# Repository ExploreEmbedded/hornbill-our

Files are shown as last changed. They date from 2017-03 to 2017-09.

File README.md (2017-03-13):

# hornbill-our
Open Univeral Remote with Hornbill ESP32 dev tools. BLE IR Bridge for device control. This is demonstration of what is possible with Hornbill ESP32 platform. To know more and support our work visit:
https://www.crowdsupply.com/explore-embedded/hornbill
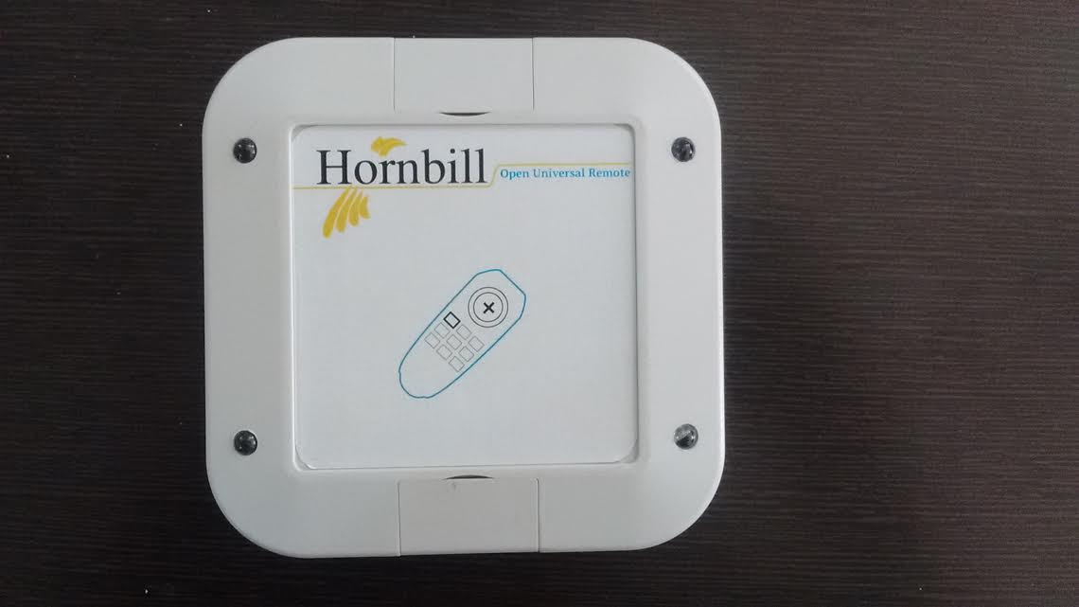
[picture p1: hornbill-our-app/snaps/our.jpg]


#ToDo
If there is enough interest in the project, we would like to add the following features:
<ul>
<li>
 Add other major IR protocols. At least the once supported by IRRemote Arduino Library 
</li>
<li>
Integrate Irdb.tk api so that remotes can be add to the app during the setup. This would require internet connection only during setup. 
</li>

<li>
RemoteMaker: Add app/firmware feature to create remotes that are not available in the database.
</li>

</ul>

If you've anyother suggestions that could be helpful, please raise on issue here on the repo. 
 
# App Screens
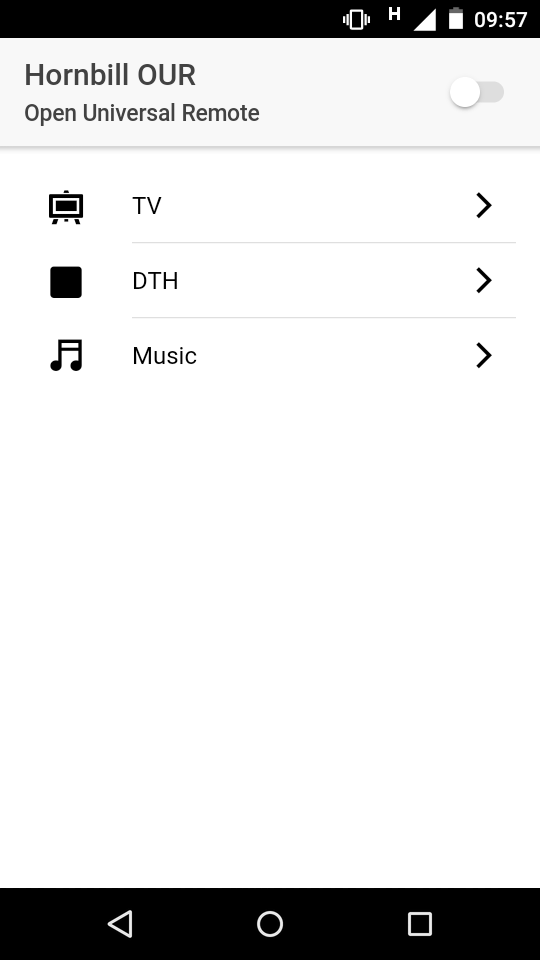
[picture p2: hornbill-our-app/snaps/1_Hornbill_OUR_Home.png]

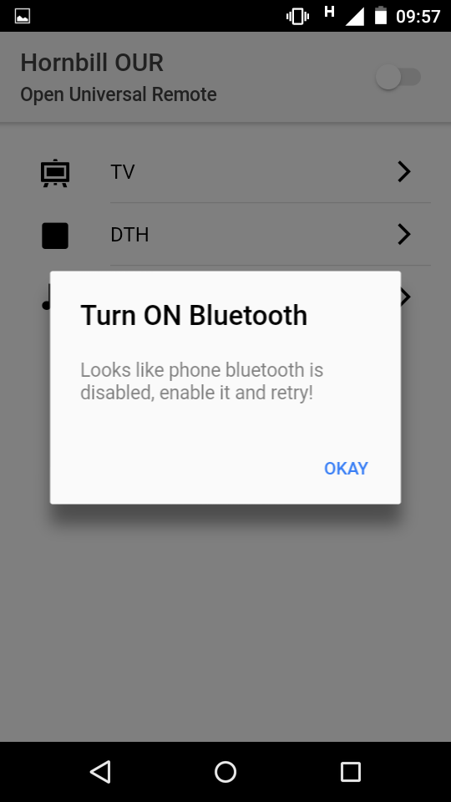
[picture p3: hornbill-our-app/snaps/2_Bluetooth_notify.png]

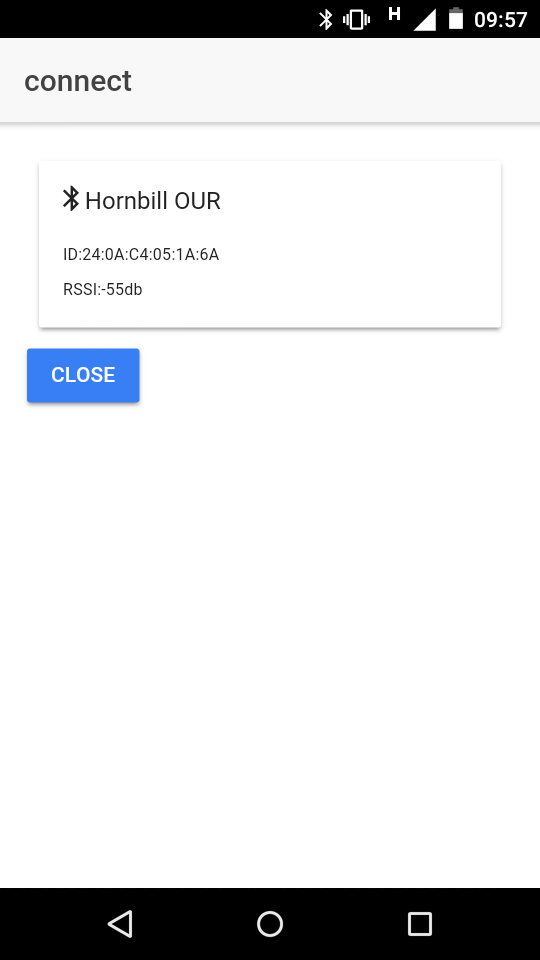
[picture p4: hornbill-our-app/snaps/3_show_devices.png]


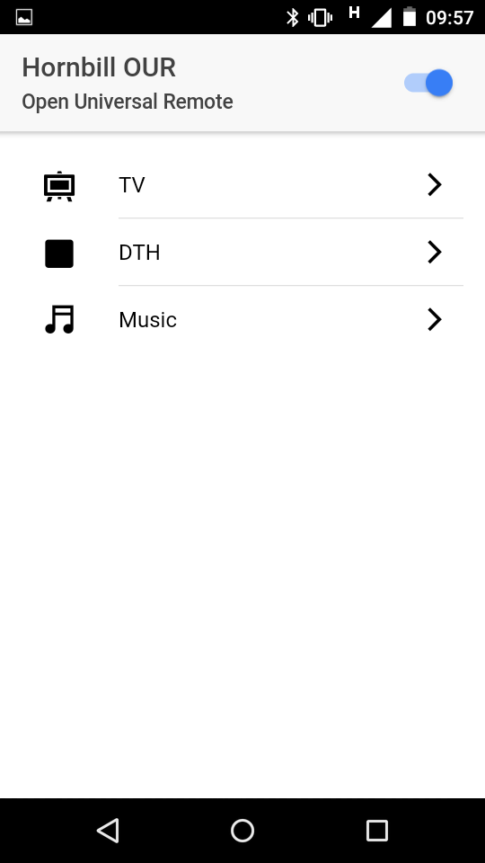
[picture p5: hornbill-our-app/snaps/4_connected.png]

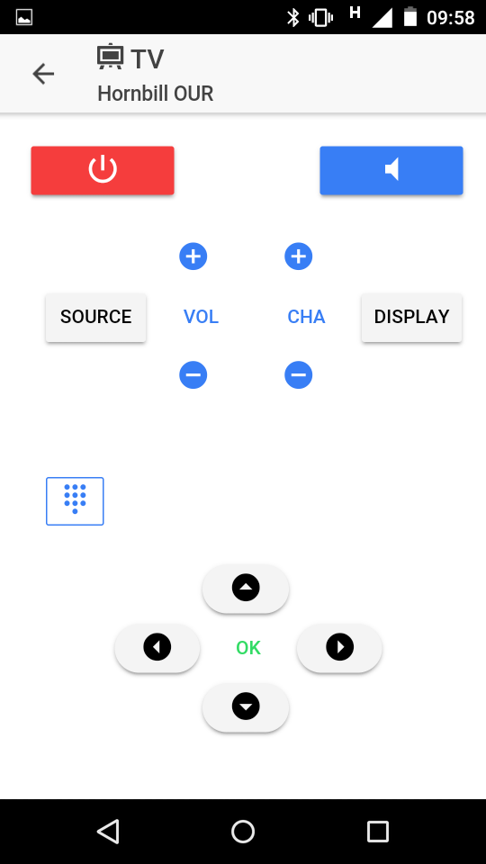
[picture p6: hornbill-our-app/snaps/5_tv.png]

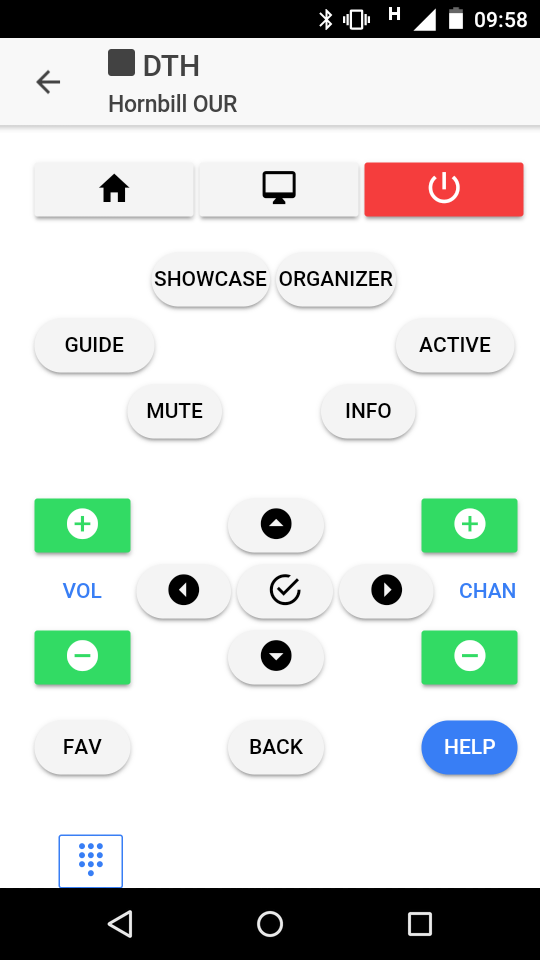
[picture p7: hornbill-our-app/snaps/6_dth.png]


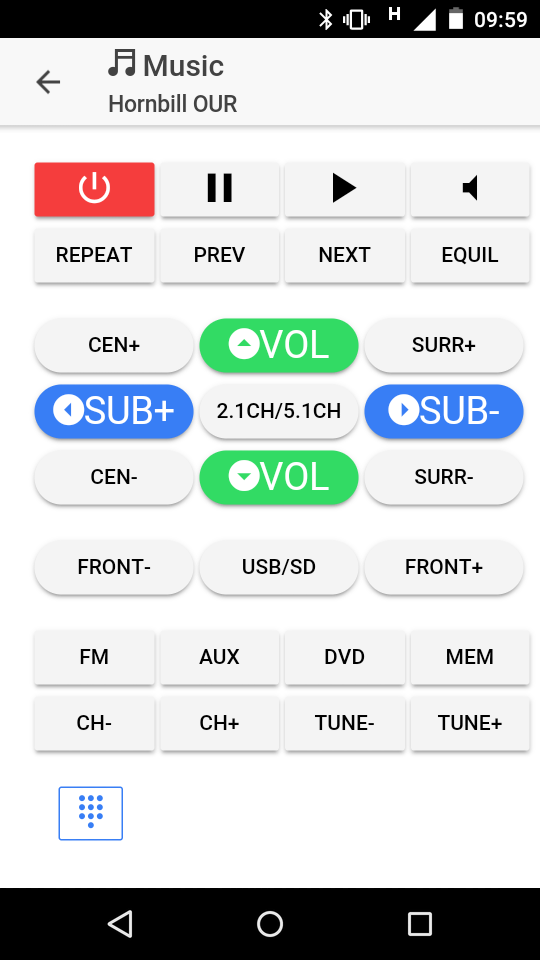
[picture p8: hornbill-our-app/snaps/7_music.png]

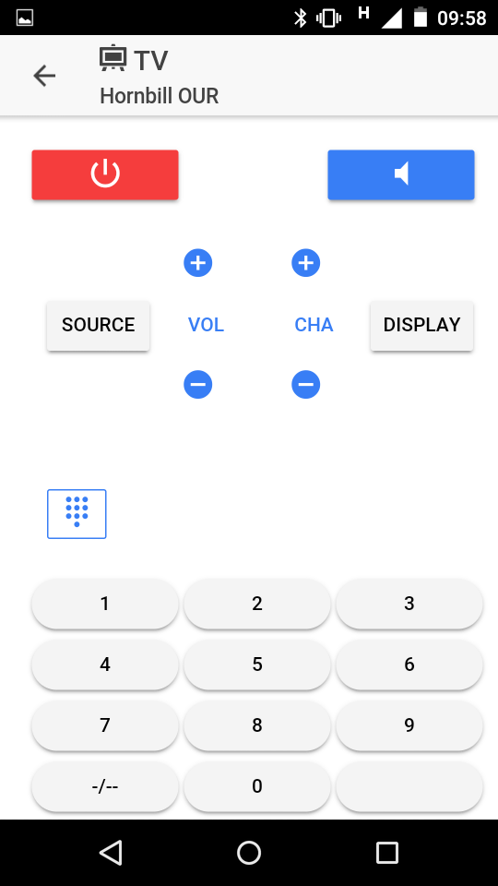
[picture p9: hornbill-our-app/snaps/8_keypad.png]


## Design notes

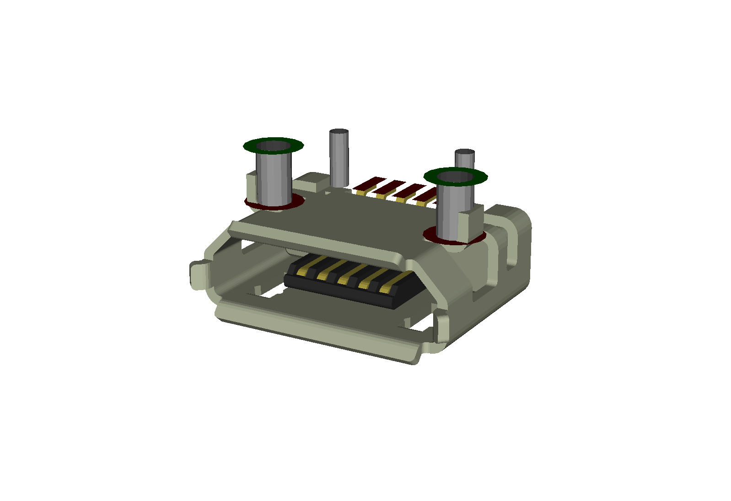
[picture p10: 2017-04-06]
Hardware/PCB/3d/micro-usb-female-type-b-connector-smd-1.snapshot.3/Renderings/AB2_USB_MICRO_SMD_2.png

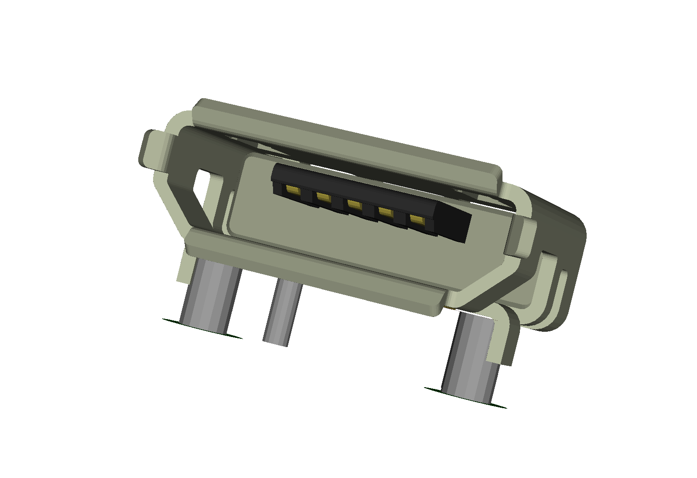
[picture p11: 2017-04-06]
Hardware/PCB/3d/micro-usb-female-type-b-connector-smd-1.snapshot.3/Renderings/AB2_USB_MICRO_SMD.png

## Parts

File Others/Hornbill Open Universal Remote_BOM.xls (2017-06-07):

Id | Designator | Package | Qty | Designation
1 | D2 | LED-0603_NEW | 1 | Blue
2 | D3 | LED-0603_NEW | 1 | LED
3 | C1 | C_1206 | 1 | 100uF
4 | C2 | C_0603 | 1 | 100nF
5 | C3 | C_0603 | 1 | 1uF
6 | C4,C5 | C_0603 | 2 | 15pF
7 | C6 | C_0603 | 1 | 2.2uF
8 | C8,C7 | C_0603 | 2 | 0.1uF
9 | CON1 | USB_Micro-B_SMD_NEW_1 | 1 | USB-MINI-B
10 | D5,D6,D9,D10 | LED-5MM | 4 | LED
11 | M1 | ESP-32S | 1 | ESP-WROOM-32
12 | P2 | Pin_Header_Straight_1x03_Pitch2.54mm | 1 | CONN_01X03
13 | R2,R10 | R_0603 | 2 | 10K
14 | R6,R9 | R_0603 | 2 | 1K
15 | R7,R8,R3,R4,R5,R11 | R_0603 | 6 | 0E
16 | R13,R23 | R_0603 | 2 | 0R
17 | R18 | R_0603 | 1 | 680R
18 | R19,R20 | R_0603 | 2 | 12K
19 | R21,R22 | R_0603 | 2 | 47R
20 | SW1,SW2 | smd_push2_New | 2 | SW_PUSH
21 | U1 | SOT-23-5 | 1 | AP2112K
25 | Y1 | SMD_RTC_Crstl | 1 | 32.768KHz RTC Crystal
26 | Q2 | SOT-23 | 1 | Q_NPN_BEC
27 | Q3,Q4 | SOT-23 | 2 | S8050
28 | P1,P3,P4,P5,P6,P7,P8,P9,P10,P11,P12,P13,P14,P15 | EE_Pin_Header_Straight_1x14_Pitch2.54mm | 14 | CONN_01X14
29 | F1 | Fuse_500mA | 1 | 500mA
30 | U9 | cp2102_xl2 | 1 | CP2102

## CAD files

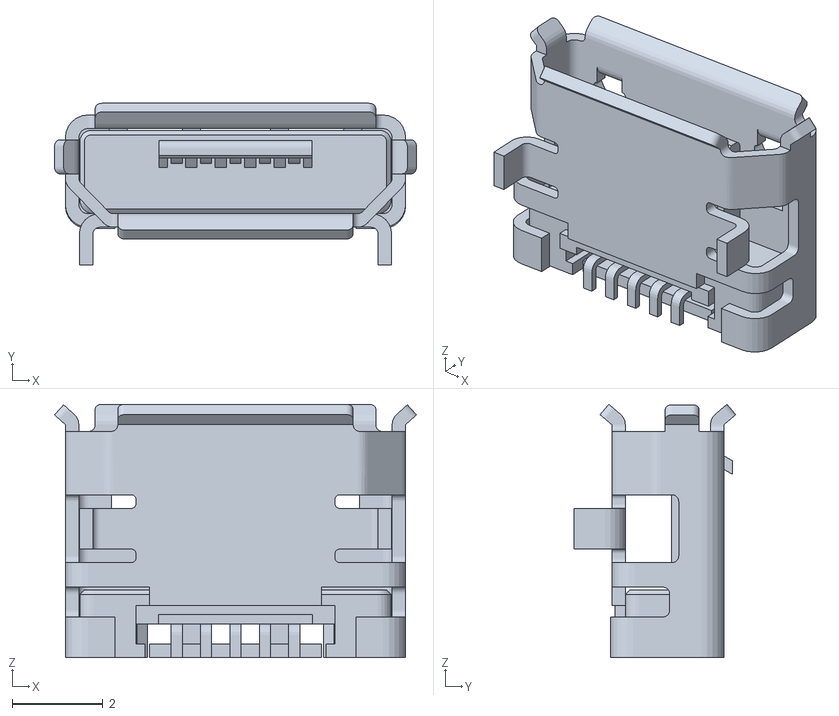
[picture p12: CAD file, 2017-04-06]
Hardware/PCB/3d/micro-usb-female-type-b-connector-smd-1.snapshot.3/AB2_USB_MICRO_SMD.stl
8.00 x 3.57 x 5.60

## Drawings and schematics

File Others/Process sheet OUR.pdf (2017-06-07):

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

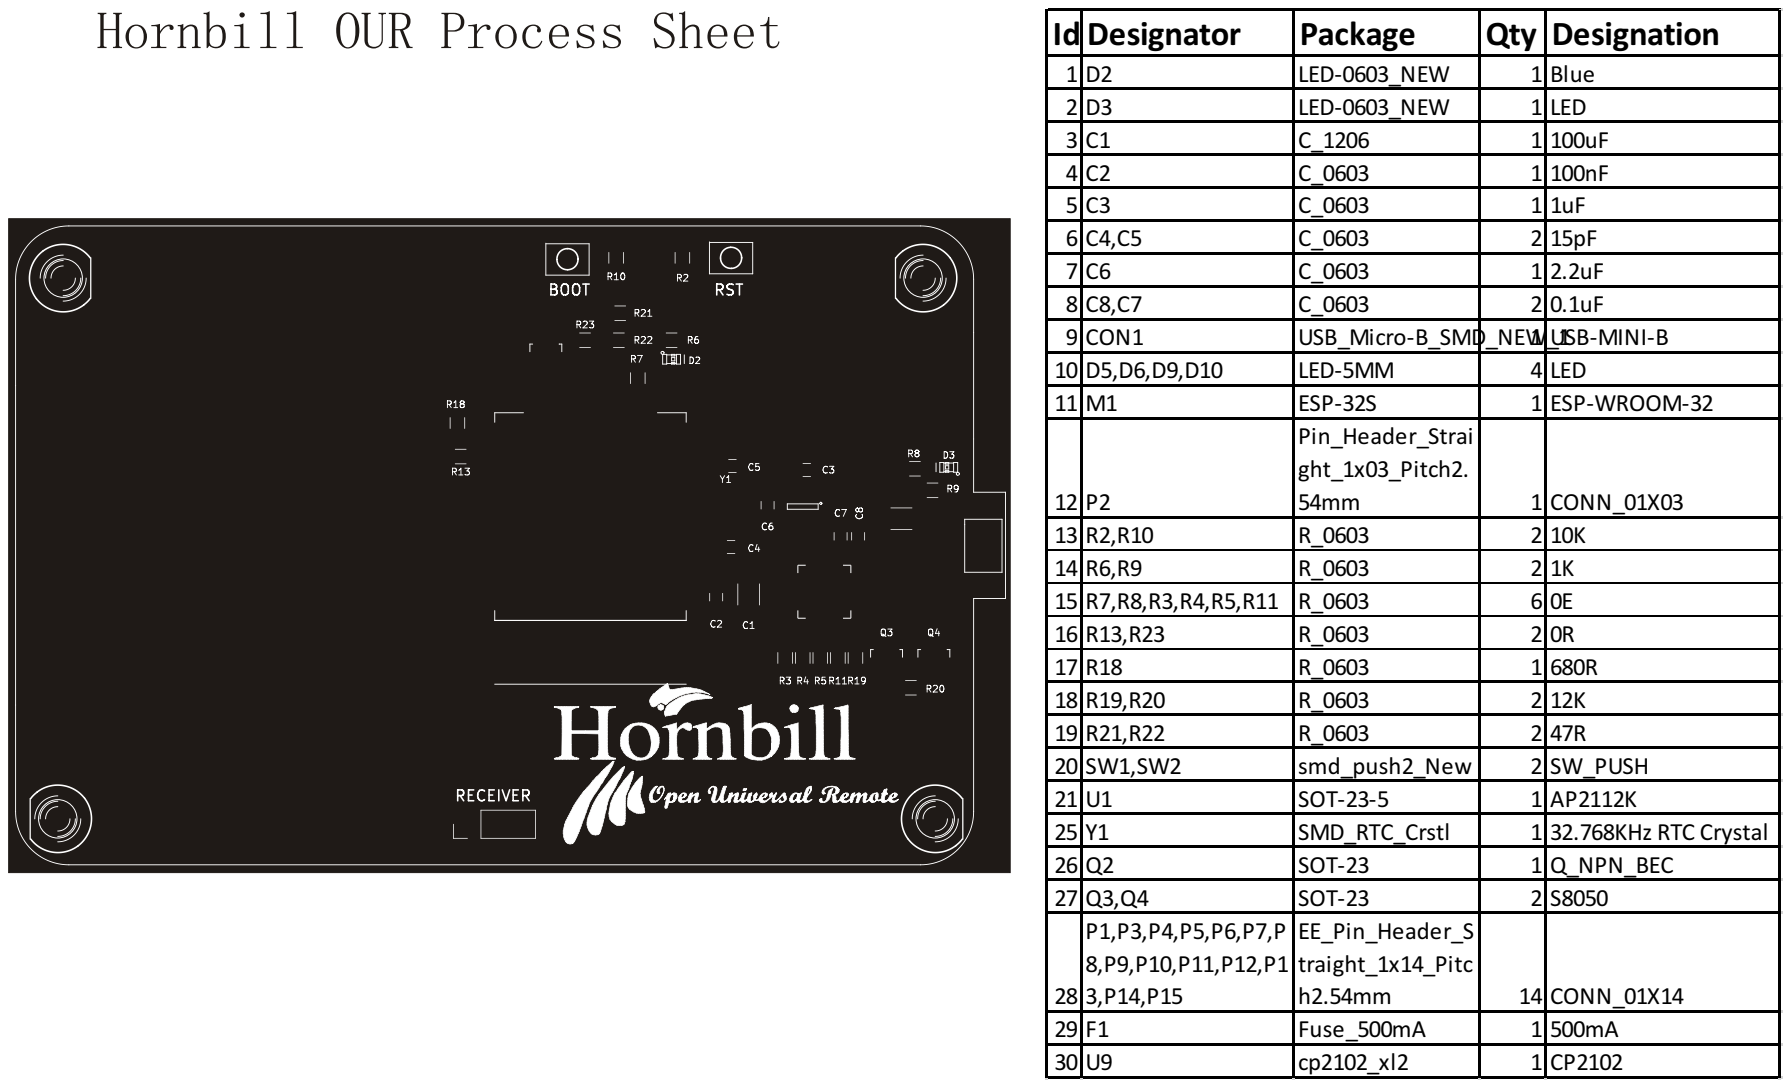
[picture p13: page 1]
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

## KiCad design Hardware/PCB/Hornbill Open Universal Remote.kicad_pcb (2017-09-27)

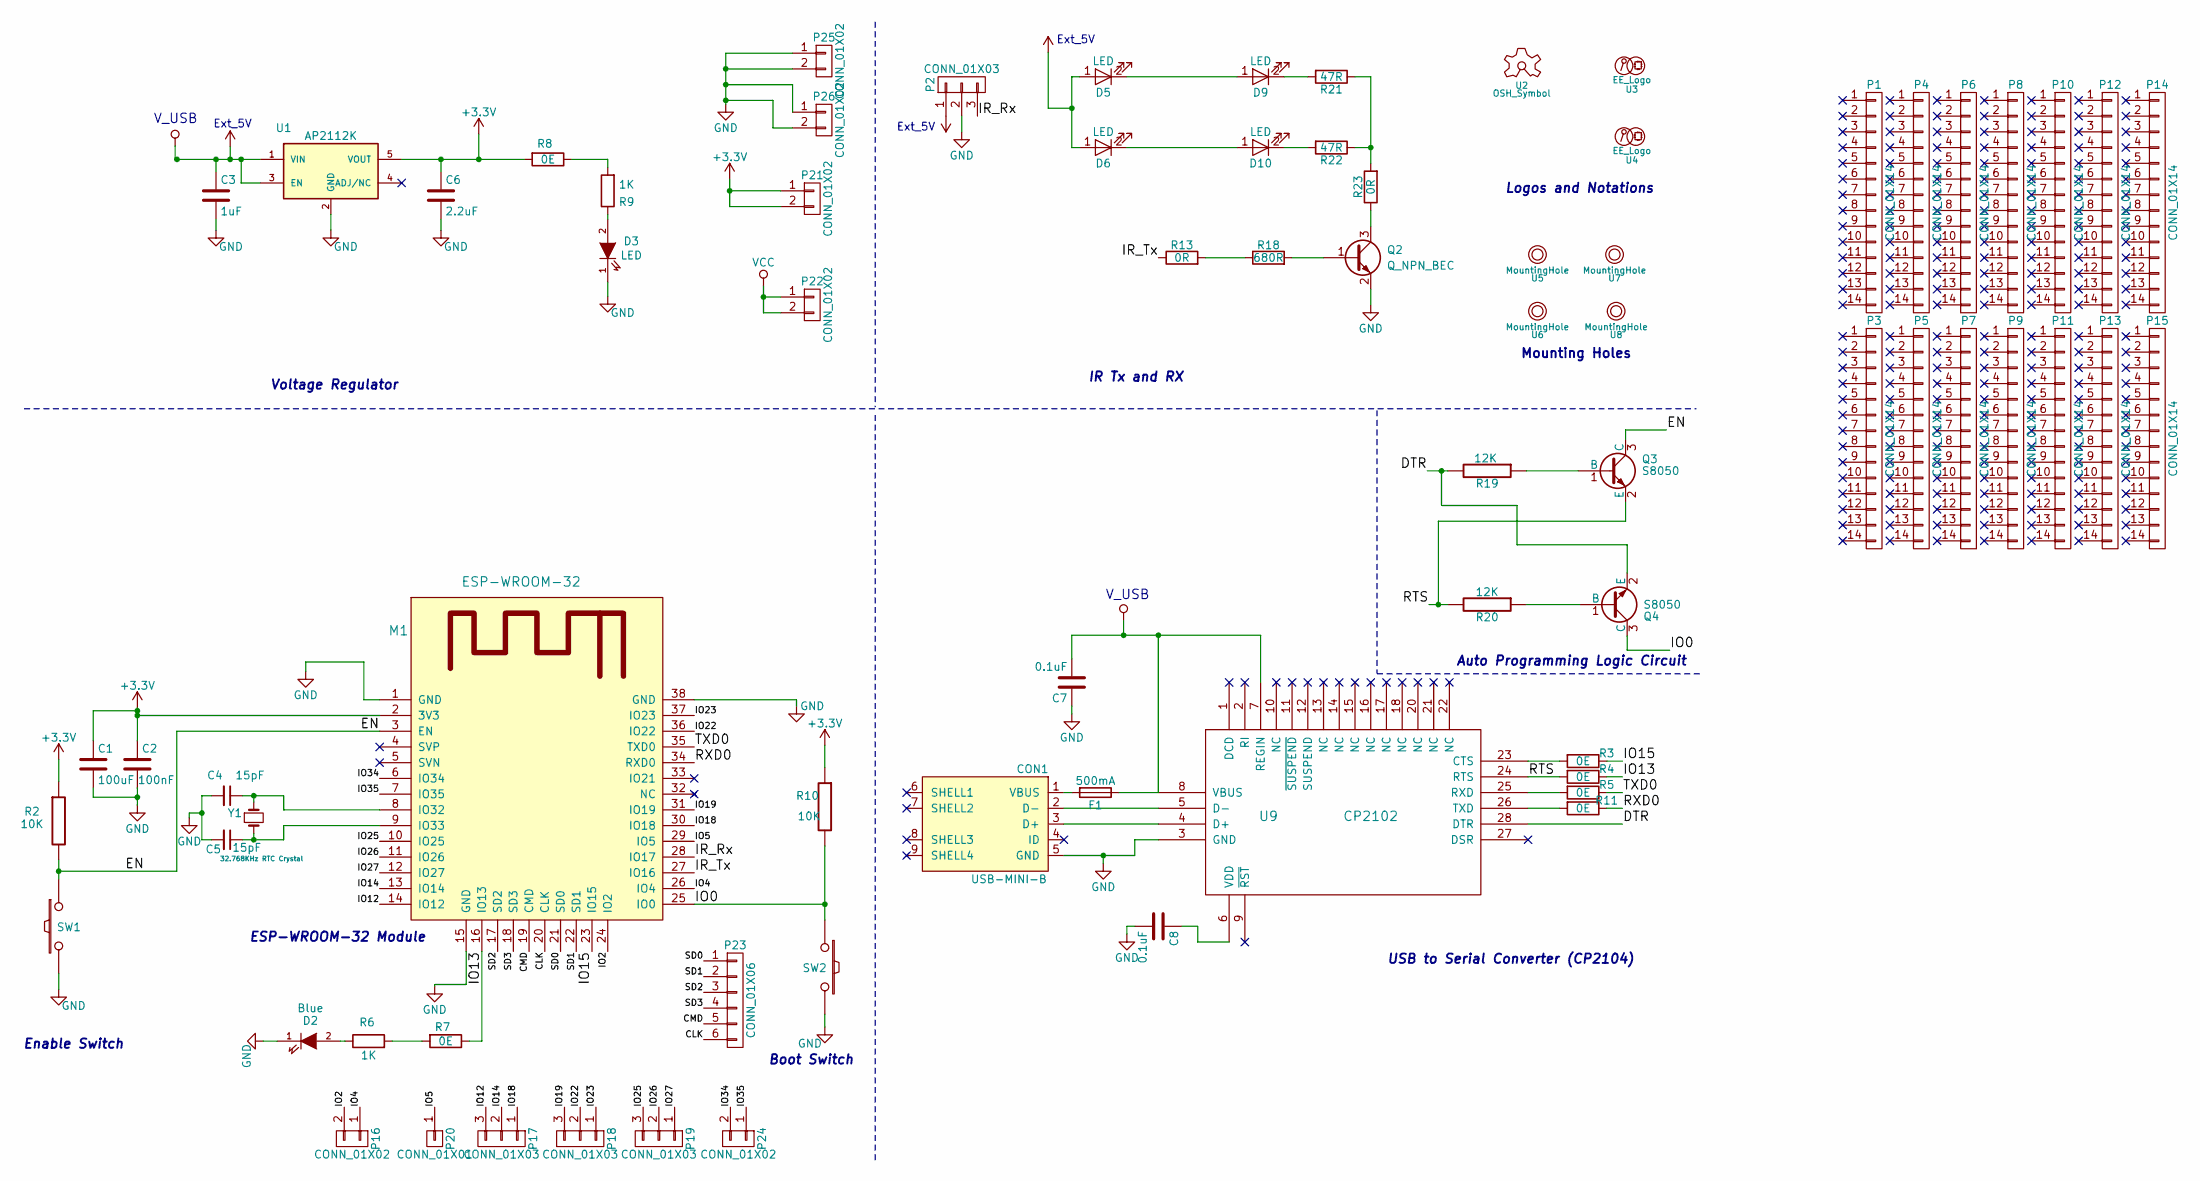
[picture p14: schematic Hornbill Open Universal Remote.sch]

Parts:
C1: 100uF; C_1206
C2: 100nF; C_0603
C3: 1uF; C_0603
C4, C5: 15pF; C_0603
C6: 2.2uF; C_0603
C7, C8: 0.1uF; C_0603
CON1: USB-MINI-B; USB_Micro-B_SMD_NEW_1
D2: Blue; LED-0603_NEW
D3: LED; LED-0603_NEW
D5, D6, D9, D10: LED; LED-5MM
F1: 500mA; Fuse_500mA
M1: ESP-WROOM-32; ESP-32S
P1, P3, P4, P5, P6, P7, P8, P9, P10, P11, P12, P13, P14, P15: CONN_01X14; EE_Pin_Header_Straight_1x14_Pitch2.54mm
P2, P17, P18, P19: CONN_01X03; Pin_Header_Straight_1x03_Pitch2.54mm
P16, P24, P25, P26: CONN_01X02; Pin_Header_Straight_1x02_Pitch2.54mm
P20: CONN_01X01; Pin_Header_Straight_1x01_Pitch2.54mm
P21, P22: CONN_01X02; Pin_Header_Straight_2x01_Pitch2.54mm
P23: CONN_01X06; Pin_Header_Straight_1x06_Pitch2.54mm
Q2: Q_NPN_BEC; SOT-23
Q3, Q4: S8050; SOT-23
R2, R10: 10K; R_0603
R3, R4, R5, R7, R8, R11: 0E; R_0603
R6, R9: 1K; R_0603
R13, R23: 0R; R_0603
R18: 680R; R_0603
R19, R20: 12K; R_0603
R21, R22: 47R; R_0603
SW1, SW2: SW_PUSH; smd_push2_New
U1: AP2112K; SOT-23-5
U2: OSH_Symbol; Logo_silk_OSHW_6x6mm
U3: EE_Logo; Hornbill_OUR
U4: EE_Logo; Logo_8
U5, U6, U7, U8: MountingHole; MountingHole_2.5mm
U9: CP2102; cp2102_xl2
Y1: 32.768KHz RTC Crystal; SMD_RTC_Crstl

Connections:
+3V3: C1.1, C2.1, C6.1, M1.2 (3V3), P21.1, P21.2, R2.1, R8.2, R10.1, U1.5 (VOUT)
+5V: C3.1, C7.2, D5.1 (A), D6.1 (A), F1.1, P2.1, P22.1, P22.2, U1.1 (VIN), U1.3 (EN), U9.7 (REGIN), U9.8 (VBUS)
/CLK: M1.20 (CLK), P23.6
/CMD: M1.19 (CMD), P23.5
/DTR: Q4.2 (E), R19.2, U9.28 (DTR)
/EN: M1.3 (EN), Q3.3 (C), R2.2, SW1.1
/IO0: M1.25 (IO0), Q4.3 (C), R10.2, SW2.1
/IO2: M1.24 (IO2), P16.2
/IO4: M1.26 (IO4), P16.1
/IO5: M1.29 (IO5), P20.1
/IO12: M1.14 (IO12), P17.3
/IO13: M1.16 (IO13), R4.1, R7.1
/IO14: M1.13 (IO14), P17.2
/IO15: M1.23 (IO15), R3.1
/IO18: M1.30 (IO18), P17.1
/IO19: M1.31 (IO19), P18.3
/IO22: M1.36 (IO22), P18.2
/IO23: M1.37 (IO23), P18.1
/IO25: M1.10 (IO25), P19.3
/IO26: M1.11 (IO26), P19.2
/IO27: M1.12 (IO27), P19.1
/IO34: M1.6 (IO34), P24.2
/IO35: M1.7 (IO35), P24.1
/IR_Rx: M1.28 (IO17), P2.3
/IR_Tx: M1.27 (IO16), R13.1
/RTS: Q3.2 (E), R4.2, R20.2, U9.24 (RTS)
/RXD0: M1.34 (RXD0), R11.1
/SD0: M1.21 (SD0), P23.1
/SD1: M1.22 (SD1), P23.2
/SD2: M1.17 (SD2), P23.3
/SD3: M1.18 (SD3), P23.4
/TXD0: M1.35 (TXD0), R5.1
GND: C1.2, C2.2, C3.2, C4.2, C5.2, C6.2, C7.1, C8.2, CON1.5 (GND), D2.1 (K), D3.1 (K), M1.1 (GND), M1.15 (GND), M1.38 (GND), P2.2, P25.1, P25.2, P26.1, P26.2, Q2.2 (E), SW1.2, SW2.2, U1.2 (GND), U9.3 (GND)
unnamed: C4.1, M1.8 (IO32), Y1.1
unnamed: C5.1, M1.9 (IO33), Y1.2
unnamed: C8.1, U9.6 (VDD)
unnamed: CON1.1 (VBUS), F1.2
unnamed: CON1.2 (D-), U9.5 (D-)
unnamed: CON1.3 (D+), U9.4 (D+)
unnamed: D2.2 (A), R6.1
unnamed: D3.2 (A), R9.1
unnamed: D5.2 (K), D9.1 (A)
unnamed: D9.2 (K), R21.2
unnamed: D6.2 (K), D10.1 (A)
unnamed: D10.2 (K), R22.2
unnamed: Q2.1 (B), R18.2
unnamed: Q2.3 (C), R23.1
unnamed: Q3.1 (B), R19.1
unnamed: Q4.1 (B), R20.1
unnamed: R3.2, U9.23 (CTS)
unnamed: R5.2, U9.25 (RXD)
unnamed: R6.2, R7.2
unnamed: R8.1, R9.2
unnamed: R11.2, U9.26 (TXD)
unnamed: R13.2, R18.1
unnamed: R21.1, R22.1, R23.2

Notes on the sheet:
Logos and Notations
Enable Switch
IR Tx and RX
Boot Switch
V_USB
Ext_5V
Voltage Regulator
Auto Programming Logic Circuit
ESP-WROOM-32 Module
USB to Serial Converter (CP2104)
Mounting Holes

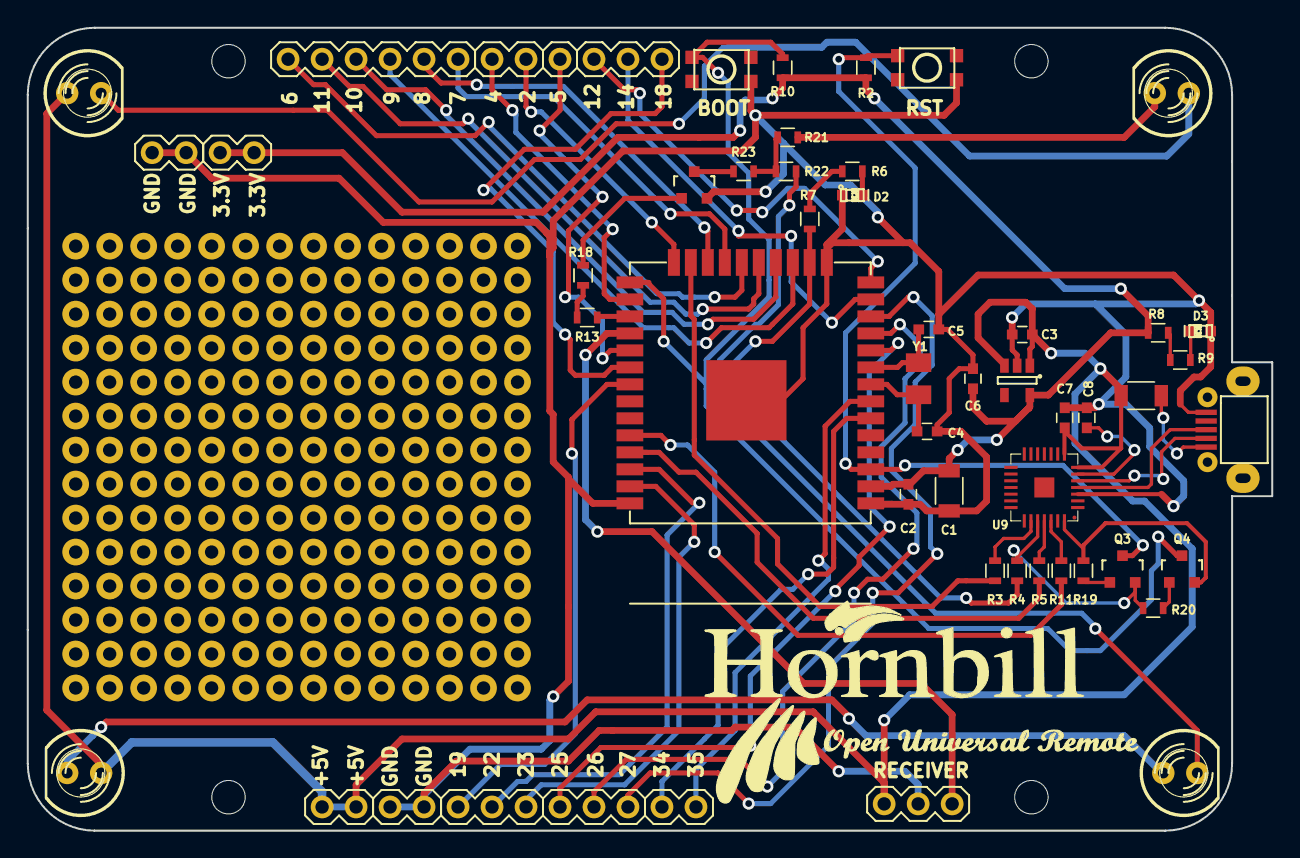
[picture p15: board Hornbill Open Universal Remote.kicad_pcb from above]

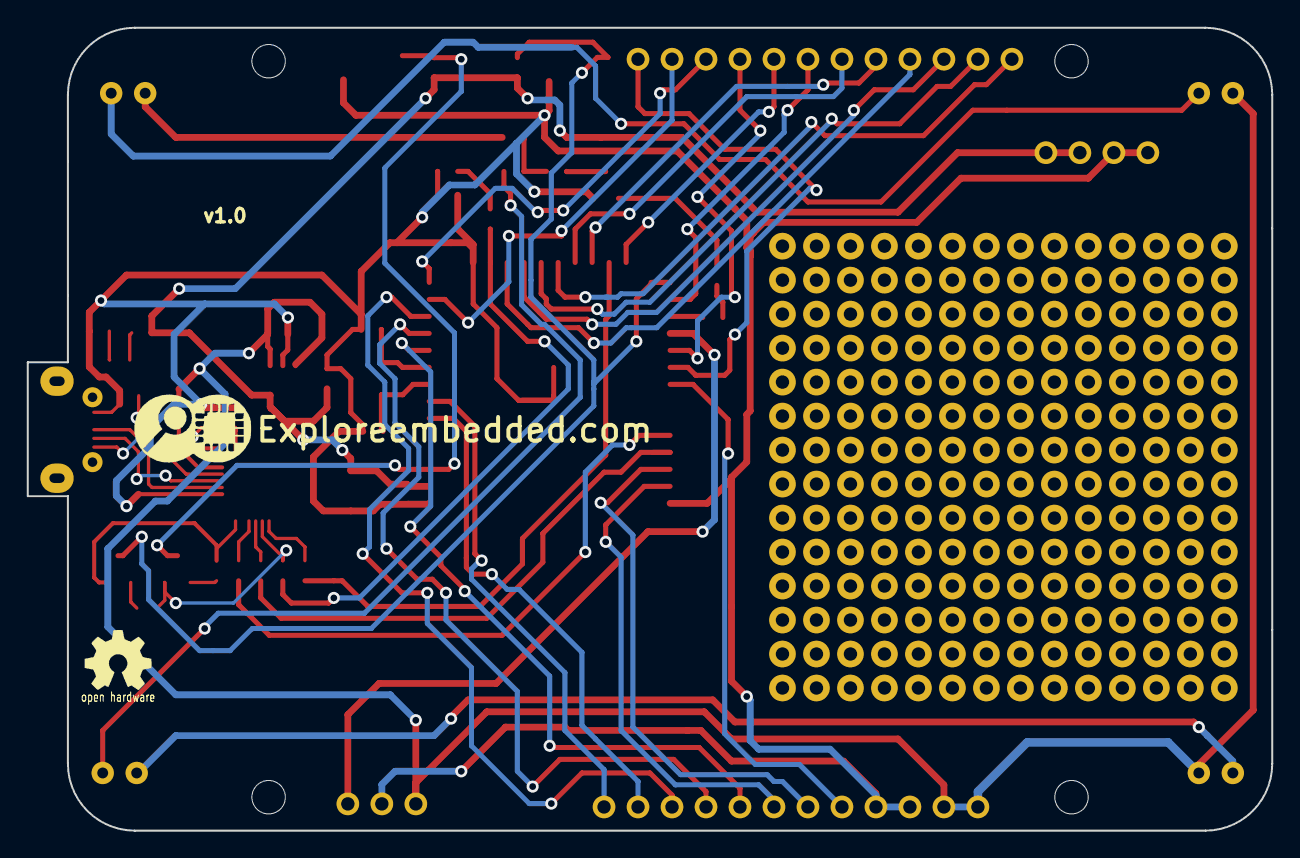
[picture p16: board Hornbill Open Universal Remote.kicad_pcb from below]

Board: 2 copper layers, 93.0 x 60.0 mm, 75 parts (2 on the bottom side), 56 nets.

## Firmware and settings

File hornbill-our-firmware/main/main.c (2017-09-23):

#include <stdio.h>
#include <stdlib.h>
#include <string.h>
#include "esp_system.h"
#include "esp_log.h" //data logging
#include "nvs_flash.h" //permnant

//hornbill our files
#include "ble.h"
extern bool receiveFlag;
extern unsigned int code[RMT_MAX_IR_CODES];

void app_main()
{
    esp_err_t ret;

    esp_bt_controller_config_t bt_cfg = BT_CONTROLLER_INIT_CONFIG_DEFAULT();
    ret = esp_bt_controller_init(&bt_cfg);
    if (ret) {
        ESP_LOGE(GATTS_TAG, "%s initialize controller failed\n", __func__);
        return;
    }

    ret = esp_bt_controller_enable(ESP_BT_MODE_BTDM);
    if (ret) {
        ESP_LOGE(GATTS_TAG, "%s enable controller failed\n", __func__);
        return;
    }
    ret = esp_bluedroid_init();
    if (ret) {
        ESP_LOGE(GATTS_TAG, "%s init bluetooth failed\n", __func__);
        return;
    }
    ret = esp_bluedroid_enable();
    if (ret) {
        ESP_LOGE(GATTS_TAG, "%s enable bluetooth failed\n", __func__);
        return;
    }

    esp_ble_gatts_register_callback(gatts_event_handler);
    esp_ble_gap_register_callback(gap_event_handler);
    esp_ble_gatts_app_register(PROFILE_A_APP_ID);
    
    receiveFlag = 0;

#ifdef CONFIG_MBEDTLS_DEBUG
    const size_t stack_size = 36*1024;
#else
    const size_t stack_size = 36*1024;
#endif

    xTaskCreatePinnedToCore(&ir_Remote_task, "ir_Remote_task", stack_size, NULL, 4, NULL, 1);

}   

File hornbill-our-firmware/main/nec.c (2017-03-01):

/* NEC remote infrared RMT example

   This example code is in the Public Domain (or CC0 licensed, at your option.)

   Unless required by applicable law or agreed to in writing, this
   software is distributed on an "AS IS" BASIS, WITHOUT WARRANTIES OR
   CONDITIONS OF ANY KIND, either express or implied.
*/
#include <stdio.h>
#include <string.h>
#include "freertos/FreeRTOS.h"
#include "freertos/task.h"
#include "freertos/queue.h"
#include "freertos/semphr.h"
#include "esp_err.h"
#include "esp_log.h"
#include "driver/rmt.h"
#include "driver/periph_ctrl.h"
#include "soc/rmt_reg.h"

static const char* NEC_TAG = "NEC";

//CHOOSE SELF TEST OR NORMAL TEST
#define RMT_RX_SELF_TEST   0

/******************************************************/
/*****                SELF TEST:                  *****/
/*Connect RMT_TX_GPIO_NUM with RMT_RX_GPIO_NUM        */
/*TX task will send NEC data with carrier disabled    */
/*RX task will print NEC data it receives.            */
/******************************************************/
#if RMT_RX_SELF_TEST
#define RMT_RX_ACTIVE_LEVEL  1   /*!< Data bit is active high for self test mode */
#define RMT_TX_CARRIER_EN    0   /*!< Disable carrier for self test mode  */
#else
//Test with infrared LED, we have to enable carrier for transmitter
//When testing via IR led, the receiver waveform is usually active-low.
#define RMT_RX_ACTIVE_LEVEL  0   /*!< If we connect with a IR receiver, the data is active low */
#define RMT_TX_CARRIER_EN    1   /*!< Enable carrier for IR transmitter test with IR led */
#endif

#define RMT_TX_CHANNEL    1     /*!< RMT channel for transmitter */
#define RMT_TX_GPIO_NUM  16     /*!< GPIO number for transmitter signal */
#define RMT_RX_CHANNEL    0     /*!< RMT channel for receiver */
#define RMT_RX_GPIO_NUM  19     /*!< GPIO number for receiver */
#define RMT_CLK_DIV      100    /*!< RMT counter clock divider */
#define RMT_TICK_10_US    (80000000/RMT_CLK_DIV/100000)   /*!< RMT counter value for 10 us.(Source clock is APB clock) */

#define NEC_HEADER_HIGH_US    9000                         /*!< NEC protocol header: positive 9ms */
#define NEC_HEADER_LOW_US     4500                         /*!< NEC protocol header: negative 4.5ms*/
#define NEC_BIT_ONE_HIGH_US    560                         /*!< NEC protocol data bit 1: positive 0.56ms */
#define NEC_BIT_ONE_LOW_US    (2250-NEC_BIT_ONE_HIGH_US)   /*!< NEC protocol data bit 1: negative 1.69ms */
#define NEC_BIT_ZERO_HIGH_US   560                         /*!< NEC protocol data bit 0: positive 0.56ms */
#define NEC_BIT_ZERO_LOW_US   (1120-NEC_BIT_ZERO_HIGH_US)  /*!< NEC protocol data bit 0: negative 0.56ms */
#define NEC_BIT_END            560                         /*!< NEC protocol end: positive 0.56ms */
#define NEC_BIT_MARGIN         20                          /*!< NEC parse margin time */

#define NEC_ITEM_DURATION(d)  ((d & 0x7fff)*10/RMT_TICK_10_US)  /*!< Parse duration time from memory register value */
#define NEC_DATA_ITEM_NUM   34  /*!< NEC code item number: header + 32bit data + end */
#define RMT_TX_DATA_NUM  100    /*!< NEC tx test data number */
#define rmt_item32_tIMEOUT_US  9500   /*!< RMT receiver timeout value(us) */

/*
 * @brief Build register value of waveform for NEC one data bit
 */
inline void nec_fill_item_level(rmt_item32_t* item, int high_us, int low_us)
{
    item->level0 = 1;
    item->duration0 = (high_us) / 10 * RMT_TICK_10_US;
    item->level1 = 0;
    item->duration1 = (low_us) / 10 * RMT_TICK_10_US;
}

/*
 * @brief Generate NEC header value: active 9ms + negative 4.5ms
 */
static void nec_fill_item_header(rmt_item32_t* item)
{
    nec_fill_item_level(item, NEC_HEADER_HIGH_US, NEC_HEADER_LOW_US);
}

/*
 * @brief Generate NEC data bit 1: positive 0.56ms + negative 1.69ms
 */
static void nec_fill_item_bit_one(rmt_item32_t* item)
{
    nec_fill_item_level(item, NEC_BIT_ONE_HIGH_US, NEC_BIT_ONE_LOW_US);
}

/*
 * @brief Generate NEC data bit 0: positive 0.56ms + negative 0.56ms
 */
static void nec_fill_item_bit_zero(rmt_item32_t* item)
{
    nec_fill_item_level(item, NEC_BIT_ZERO_HIGH_US, NEC_BIT_ZERO_LOW_US);
}

/*
 * @brief Generate NEC end signal: positive 0.56ms
 */
static void nec_fill_item_end(rmt_item32_t* item)
{
    nec_fill_item_level(item, NEC_BIT_END, 0x7fff);
}

/*
 * @brief Check whether duration is around target_us
 */
inline bool nec_check_in_range(int duration_ticks, int target_us, int margin_us)
{
    if(( NEC_ITEM_DURATION(duration_ticks) < (target_us + margin_us))
        && ( NEC_ITEM_DURATION(duration_ticks) > (target_us - margin_us))) {
        return true;
    } else {
        return false;
    }
}

/*
 * @brief Check whether this value represents an NEC header
 */
static bool nec_header_if(rmt_item32_t* item)
{
    if((item->level0 == RMT_RX_ACTIVE_LEVEL && item->level1 != RMT_RX_ACTIVE_LEVEL)
        && nec_check_in_range(item->duration0, NEC_HEADER_HIGH_US, NEC_BIT_MARGIN)
        && nec_check_in_range(item->duration1, NEC_HEADER_LOW_US, NEC_BIT_MARGIN)) {
        return true;
    }
    return false;
}

/*
 * @brief Check whether this value represents an NEC data bit 1
 */
static bool nec_bit_one_if(rmt_item32_t* item)
{
    if((item->level0 == RMT_RX_ACTIVE_LEVEL && item->level1 != RMT_RX_ACTIVE_LEVEL)
        && nec_check_in_range(item->duration0, NEC_BIT_ONE_HIGH_US, NEC_BIT_MARGIN)
        && nec_check_in_range(item->duration1, NEC_BIT_ONE_LOW_US, NEC_BIT_MARGIN)) {
        return true;
    }
    return false;
}

/*
 * @brief Check whether this value represents an NEC data bit 0
 */
static bool nec_bit_zero_if(rmt_item32_t* item)
{
    if((item->level0 == RMT_RX_ACTIVE_LEVEL && item->level1 != RMT_RX_ACTIVE_LEVEL)
        && nec_check_in_range(item->duration0, NEC_BIT_ZERO_HIGH_US, NEC_BIT_MARGIN)
        && nec_check_in_range(item->duration1, NEC_BIT_ZERO_LOW_US, NEC_BIT_MARGIN)) {
        return true;
    }
    return false;
}


/*
 * @brief Parse NEC 32 bit waveform to address and command.
 */
static int nec_parse_items(rmt_item32_t* item, int item_num, uint16_t* addr, uint16_t* data)
{
    int w_len = item_num;
    //if lenght of items passed is less than 34 return back
    if(w_len < NEC_DATA_ITEM_NUM) {
        return -1;
    }
    int i = 0, j = 0;
    if(!nec_header_if(item++)) {
        return -1;
    }
    uint16_t addr_t = 0;
    for(j = 0; j < 16; j++) {
        if(nec_bit_one_if(item)) {
            addr_t |= (1 << j);
        } else if(nec_bit_zero_if(item)) {
            addr_t |= (0 << j);
        } else {
            return -1;
        }
        item++;
        i++;
    }
    uint16_t data_t = 0;
    for(j = 0; j < 16; j++) {
        if(nec_bit_one_if(item)) {
            data_t |= (1 << j);
        } else if(nec_bit_zero_if(item)) {
            data_t |= (0 << j);
        } else {
            return -1;
        }
        item++;
        i++;
    }
    *addr = addr_t;
    *data = data_t;
    return i;
}
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

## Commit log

2017-04-06 Added Design Files
    [AB2_USB_MICRO_SMD.stl, Hornbill Open Universal Remote.kicad_pcb, Hornbill Open Universal Remote.sch]
2017-05-01 Hornbill logo added for OUR
    [Hornbill Open Universal Remote.kicad_pcb, Hornbill Open Universal Remote.sch]
2017-06-07 BOM,process sheet added
    [Hornbill Open Universal Remote.csv, Hornbill Open Universal Remote_BOM.xls]
2017-08-21 Used esp32 RMT for sending the IR codes. Renamed the old hornbill firmare folder.
2017-08-24 Added support for different Tx frequency
    Added support for different Tx frequency without doing rmt driver
    install and uninstall each time.
    Also changed code to fix IR Tx freq issue.
    [esp32_rmt.c, esp32_rmt.h, main.c]
2017-09-20 IO pins taken out
    [Hornbill Open Universal Remote.kicad_pcb, Hornbill Open Universal Remote.sch]
2017-09-21 PCB legends renamed and gerber file generated
    [Hornbill Open Universal Remote-B.Cu.gbr, Hornbill Open Universal Remote-B.Mask.gbr, Hornbill Open Universal Remote-B.SilkS.gbr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]
2017-09-23 Updated esp32_rmt files to fix timing issues
    Also removed redudant code
    [esp32_rmt.c, esp32_rmt.h, main.c]
2017-09-27 Legend modified and gerber file generated
    [Hornbill Open Universal Remote-B.Cu.gbr, Hornbill Open Universal Remote-B.Mask.gbr, Hornbill Open Universal Remote-B.SilkS.gbr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]
